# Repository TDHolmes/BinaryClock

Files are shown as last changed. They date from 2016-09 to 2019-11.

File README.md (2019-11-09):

# Binary Clock
A simple but well designed clock that displays the time in [binary coded decimal][BCD wiki link]

## PCB

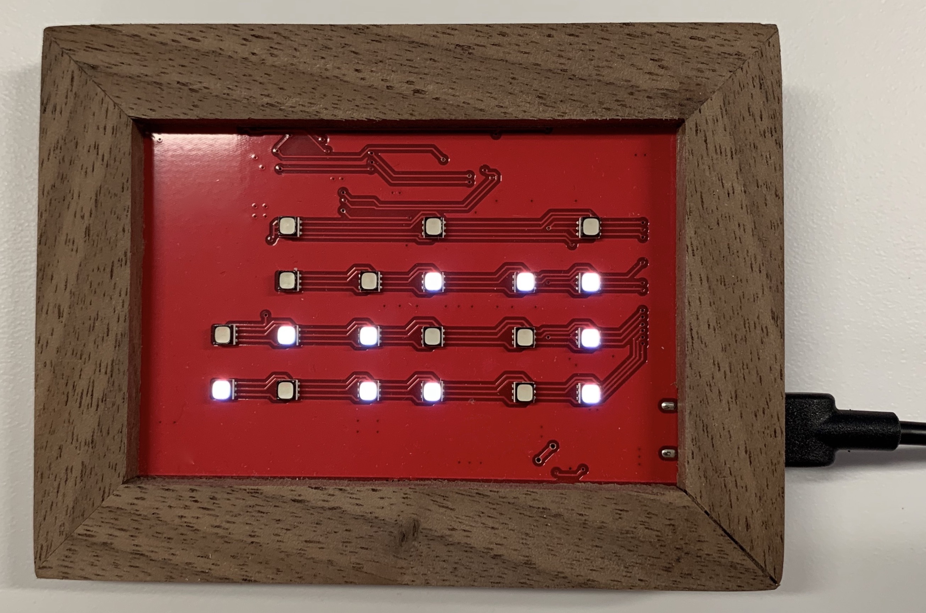
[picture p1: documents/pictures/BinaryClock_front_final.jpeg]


The current design uses an Atmel [ATtiny4313][attiny link] microcontroller in conjunction with a Maxim [DS3231M][ds3231m link] [RTC][RTC wiki link] for accurate time keeping. The LEDs are driven with a [STP16CPC26][stp16cpc26 link] constant current LED driver along with [high-side MOSFETs][mosfet wiki link] for [multiplexing][multiplexing wiki link].

## LED Driving Scheme

The LEDs are driven by multiplexing the rows and columns. The columns are dirven individually via PMOS transistors. The rows are daisy chained and driven by the [STP16CPC26][stp16cpc26 link]. The columns are refreshed at an effective rate of 360 Hz to be equivallent to 60 Hz refresh rate.

In order to get more than basic red, green and blue combinations, the LEDs have four time slots to create more color combinations. So in reality, the LEDs are updated at (60 Hz) * (6 columns) * (4 bit color) = 1440 Hz.

Below shows the connectivity of the LEDs to the driver chips.



Below is a snapshot in time when the minute ones column is active.



Below is a gif of multiplexing in action.

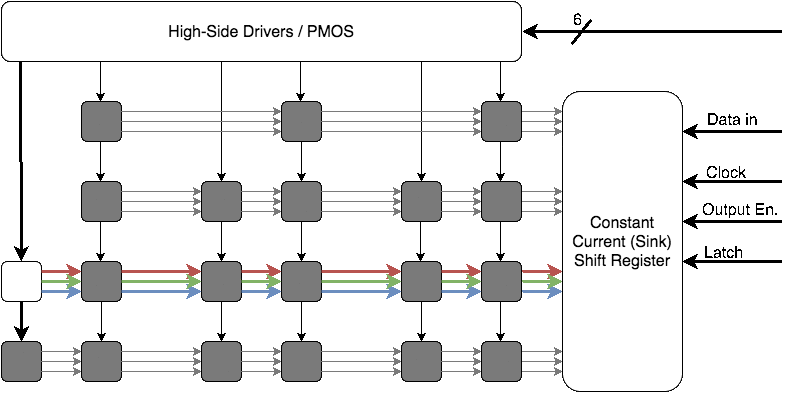
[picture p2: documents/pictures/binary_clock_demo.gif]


## GUI
The user interface communicates to the PCB via a [UART][UART wiki link] through a USB to serial converter chip. The user interface can do a few things:
- set the time to the current computer system time
- set a custom time
- set one or all LEDs to a certain color
- clear one or all LEDs

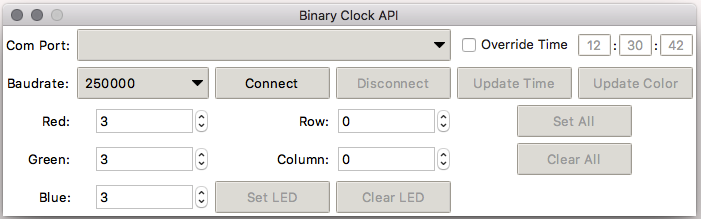
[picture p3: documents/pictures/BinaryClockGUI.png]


[BCD wiki link]: https://en.wikipedia.org/wiki/Binary-coded_decimal
[attiny link]: http://www.atmel.com/devices/ATTINY4313.aspx
[ds3231m link]: https://www.maximintegrated.com/en/products/digital/real-time-clocks/DS3231M.html
[stp16cpc26 link]: http://www.st.com/content/st_com/en/products/power-management/led-drivers/led-array-drivers/stp16cpc26.html
[Multiplex - off]: https://raw.githubusercontent.com/TDHolmes/BinaryClock/master/documents/pictures/binaryClock_multiplexLogic_notOn.png "Diagram of the connections if the LEDs"
[Multiplex - on]: https://raw.githubusercontent.com/TDHolmes/BinaryClock/master/documents/pictures/binaryClock_multiplexLogic_on.png "Diagram of a snapshot when the minute ones column is active."
[Multiplex - gif]: https://raw.githubusercontent.com/TDHolmes/BinaryClock/master/documents/pictures/binary_clock_demo.gif "Live gif of the multiplexing."
[PCB picture]: https://raw.githubusercontent.com/TDHolmes/BinaryClock/master/documents/pictures/BinaryClock_front_final.jpeg "final Binary Clock displaying 12:35:47"
[RTC wiki link]: https://en.wikipedia.org/wiki/Real-time_clock
[mosfet wiki link]: https://en.wikipedia.org/wiki/MOSFET#Single-type
[multiplexing wiki link]: https://en.wikipedia.org/wiki/Multiplexing
[GUI picture]: https://raw.githubusercontent.com/TDHolmes/BinaryClock/master/documents/pictures/BinaryClockGUI.png "Binary Clock GUI v1.0"
[UART wiki link]: https://en.wikipedia.org/wiki/Universal_asynchronous_receiver/transmitter

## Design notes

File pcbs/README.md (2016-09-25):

# Binary-Clock-v2.0
Board and schematic for the binary clock project.

<br />This work is licensed under a <a rel="license" href="http://creativecommons.org/licenses/by-nc-sa/4.0/">Creative Commons Attribution-NonCommercial-ShareAlike 4.0 International License</a>.

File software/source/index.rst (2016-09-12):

.. Binary Clock Software documentation master file, created by
   sphinx-quickstart on Sun Sep 11 17:31:34 2016.
   You can adapt this file completely to your liking, but it should at least
   contain the root `toctree` directive.

Welcome to Binary Clock Software's documentation!
=================================================

.. toctree::
   :maxdepth: 2

Binary Clock Python API
-----------------------

.. automodule:: binaryClockAPI

=====================
BinaryClockAPI Class
=====================

.. currentmodule:: binaryClockAPI
.. autoclass:: BinaryClockAPI
    :private-members:
    :members:

Binary Clock GUI
----------------

.. automodule:: binaryClockGUI

=====================
BinaryClockGUI Class
=====================

.. currentmodule:: binaryClockGUI
.. autoclass:: BinaryClockGUI
    :private-members:
    :members:

GUI Helper Functions
--------------------

.. automodule:: CustomGUIWrappers
.. currentmodule:: CustomGUIWrappers

=================
CheckBox Class
=================

.. autoclass:: CheckBox 
   :private-members:
   :members:

=================
EntryBox Class
=================

.. autoclass:: EntryBox 
   :private-members:
   :members:

=================
Dropdown Class
=================

.. autoclass:: Dropdown 
   :private-members:
   :members:

============
Labels Class
============

.. autoclass:: Labels 
   :private-members:
   :members:

=================
ScrollBox Class
=================

.. autoclass:: ScrollBox 
   :private-members:
   :members:

============
Button Class
============

.. autoclass:: Button 
   :private-members:
   :members:

=================
TimeEntry Class
=================

.. autoclass:: TimeEntry 
   :private-members:
   :members:

Indices and tables
==================

* :ref:`genindex`
* :ref:`modindex`
* :ref:`search`

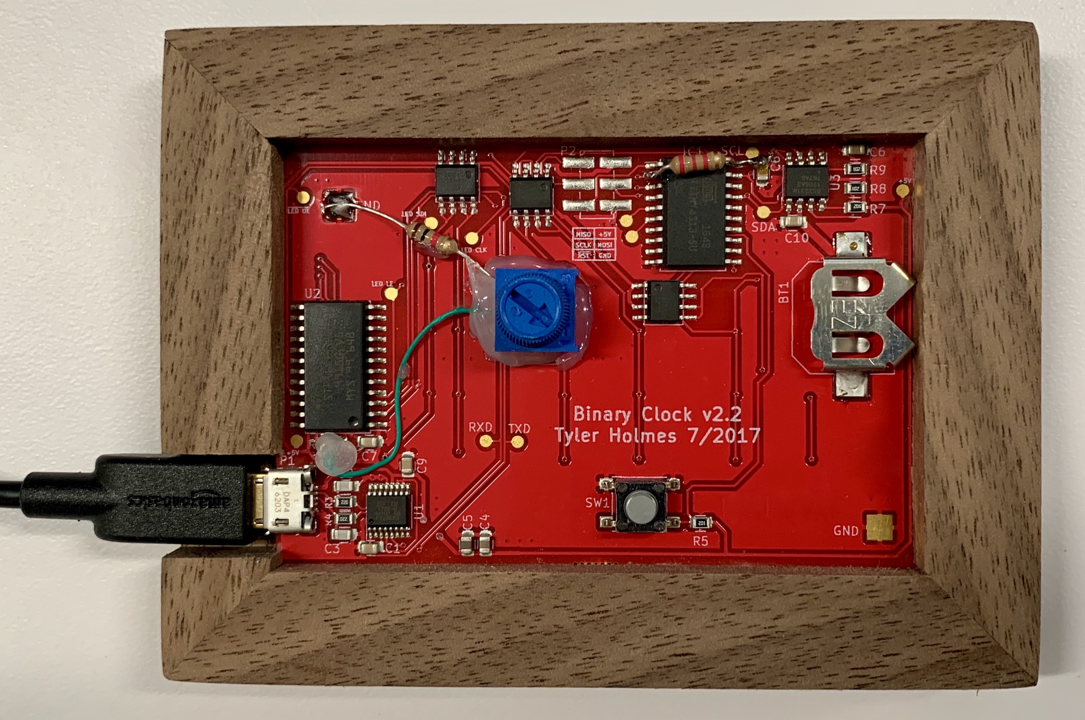
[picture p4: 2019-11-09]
documents/pictures/BinaryClock_back_final.jpeg

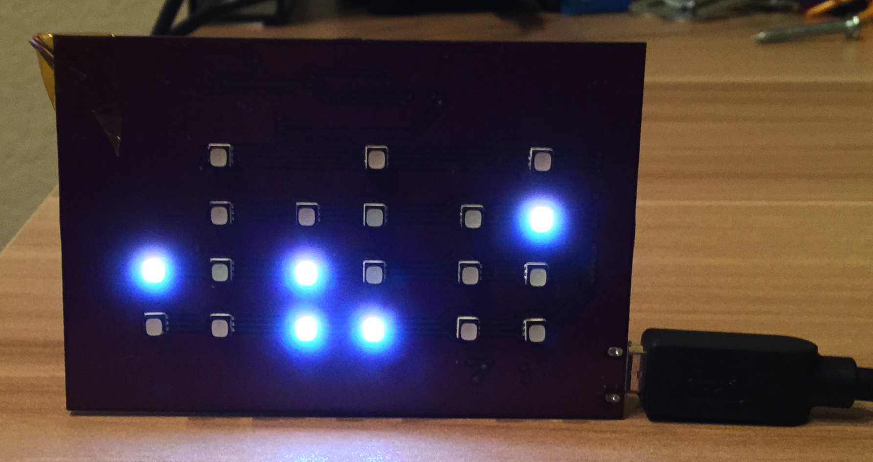
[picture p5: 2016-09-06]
documents/pictures/BinaryClock_rev1.JPG

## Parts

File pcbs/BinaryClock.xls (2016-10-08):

Id | Designator | Package | Quantity | Designation | MPN
3 | C3,C2 | C_0805 | 2 | 47 pF | 885012007032
4 | C4 | C_0805 | 1 | 1 uF | CC0805KKX7R7BB105
6 | C5 | C_0805 | 1 | 4.7 uF | GRM21BR61E475KA12L
7 | Q2,Q1,Q3 | SOIC-8-N | 3 | DMG9933USD | DMG9933USD-13DICT-ND
8 | BT1 | S8201-46R | 1 | CR1220 | S8201-46R
9 | U3 | SOIC-8_3.9x4.9mm_Pitch1.27mm | 1 | DS3231M | DS3231MZ/V+
10 | IC1 | SOIC-20_7.5x12.8mm_Pitch1.27mm | 1 | ATTINY2313A-S | ATtiny4313
11 | D_M_8,D_S_40,D_S_20,D_S_10,D_S_8,D_S_4,D_S_2,D_S_1,D_M_40,D_M_20,D_M_10,D_M_4,D_M_2,D_M_1,D_H_20,D_H_10,D_H_8,D_H_4,D_H_2,D_H_1 | CREELED_6 | 20 | CLY6D-FKC | CLY6D-FKC-CK1N1D1BB7D3D3
12 | SW1 | SW_SPST_PTS645 | 1 | SW_PUSH | PTS645SH50SMTR92 LFS
13 | R5,R9,R8,R7 | R_0805 | 4 | 1K | RC0805JR-071KL
14 | R6 | R_0805 | 1 | 2K | RC0805JR-072KL
15 | R3,R4 | R_0805 | 2 | R27 | RC0805JR-0727RL
16 | P1 | 2013499-1 | 1 | USB_OTG | 2013499-1
17 | U2 | SOIC-24_7.5x15.4mm_Pitch1.27mm | 1 | STP16CPC26 | STP16CPC26MTR
18 | P2 | 2x3_header_smd_0.1in | 1 | CONN_02X03 | 15910060
19 | U1 | SSOP-16_3.9x4.9mm_Pitch0.635mm | 1 | FT230XS | FT230XS-U
20 | C1 | C_0805 | 1 | 0.1 uF | C0805C104K3RACTU
21 | C7,C10,C6,C8,C9 | C_0805 | 6 | 0.1 uF | C0805C104K3RACTU

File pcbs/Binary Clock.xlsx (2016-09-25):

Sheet: Parts
Qty | Part Number | Description | Cost per 1 | Cost per 100 | Net (per 1) | Net (per 100) | datasheet
1 | STP16CPC26MTR | 16 bit constant current sink | $0.75 | $0.57 | $0.75 | $0.57 | http://www.st.com/content/ccc/resource/technical/document/datasheet/5c/ed/b3/8b/32/99/4d/cd/CD00298756.pdf/files/CD00298756.pdf/jcr:content/translations/en.CD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
1 | ATtiny4313 | ATtiny 20 MHz 8-Bit Micro - SOIC-20 | $1.84 | $1.33 | $1.84 | $1.33 | http://www.atmel.com/images/doc8246.pdf
20 | CLY6D-FKC-CK1N1D1BB7D3D3 | RGB LED | $0.37 | $0.32 | $7.40 | $6.40 | http://www.cree.com/~/media/Files/Cree/LED-Components-and-Modules/HB/Data-Sheets/1321-CLY6D-FKC.pdf
3 | DMG9933USD-13DICT-ND | P-FET transistors. pair (SOIC-8) | $0.41 | $0.26 | $1.23 | $0.78 | http://www.diodes.com/_files/datasheets/ds32085.pdf
1 | FT230XS-U | USB to serial converter | $2.04 | $1.90 | $2.04 | $1.90 | http://www.ftdichip.com/Support/Documents/DataSheets/ICs/DS_FT230X.pdf
1 | 2013499-1 | micro USB connector | $1.78 | $1.38 | $1.78 | $1.38 | http://www.te.com/usa-en/product-2013499-1.html
1 | DS3231MZ/V+ | High Accuracy RTC w/ internal osc. | $6.46 | $4.81 | $6.46 | $4.81 | https://datasheets.maximintegrated.com/en/ds/DS3231M.pdf
1 | 15910060 | 6 pos prog header | $0.57 | $0.37 | $0.57 | $0.37 | http://www.digikey.com/product-detail/en/molex-llc/0015916062/WM6888CT-ND/3044894
1 | PTS645SH50SMTR92 LFS | tac switch | $0.21 | $0.18 | $0.21 | $0.18 | http://www.ck-components.com/media/1471/pts645.pdf
6 |  | 1k resistors
1 |  | 2k resistors |  |  |  |  | Dimensions (in): | 2 | 3
4 |  | .1 uF
1 |  | 1 uF
2 |  | 10 uF
 |  |  |  | Total: | $22.28 | $17.71
 | Board Fabrication, 2 layer | PCB Way |  | $1.51 |  | $0.00
1 |  | Dirty PCB |  | $2.42 |  | $2.42
 |  | Sunstone (USA) |  | $7.66 |  | $0.00
1 | Fab | PCB-CART |  | $4.15 |  | $7.40
 |  | PCB-NG |  | $72.00 |  | $0.00
 |  | PCB Assembly Express |  | $7.70 |  | $0.00
 |  |  |  |  | Total: | $9.82
 |  |  |  | Grand Total: | $32.10 | $27.53
 | Cost for 100: |  |  | Cost for X: | 50 | $1,376.57
 |  |  |  | Price Sold At: |  | $64.20
 |  |  |  | Number sold to recop |  | 22
 |  |  |  | Total Profit: |  | $1,833.21
 | SMD Trimmer | http://www.digikey.com/product-detail/en/copal-electronics-inc/ST4ETB102/ST4ETB102CT-ND/738512

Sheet: Sheet3
Qty | Part Number | Description
1 | STP16CPC26MTR | 16 bit constant current sink
1 | ATtiny4313 | ATtiny 20 MHz 8-Bit Micro - SOIC-20
20 | CLY6D-FKC-CK1N1D1BB7D3D3 | RGB LED
3 | DMG9933USD-13DICT-ND | P-FET transistors. pair (SOIC-8)
1 | FT230XS-U | USB to serial converter
1 | 2013499-1 | micro USB connector
1 | DS3231MZ/V+ | High Accuracy RTC w/ internal osc.
1 | 15910060 | 6 pos prog header
1 | PTS645SH50SMTR92 LFS | tac switch
6 |  | 1k resistors
1 |  | 2k resistors
4 |  | .1 uF
1 |  | 1 uF
2 |  | 10 uF

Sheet: Timing
Attiny Frequency: | 8,000,000 | Hz
Clks per bit: | 40 | clks | (1/2 the freqency of the micro + 16 data bits + Latching & output)
N bit Color: | 8 | bits
N rows to multiplex: | 12
Total Update Rate | 120 | Hz
Wait Time per Bit: | 0.562 | ms
Setup Time per Bit: | 0.480 | ms

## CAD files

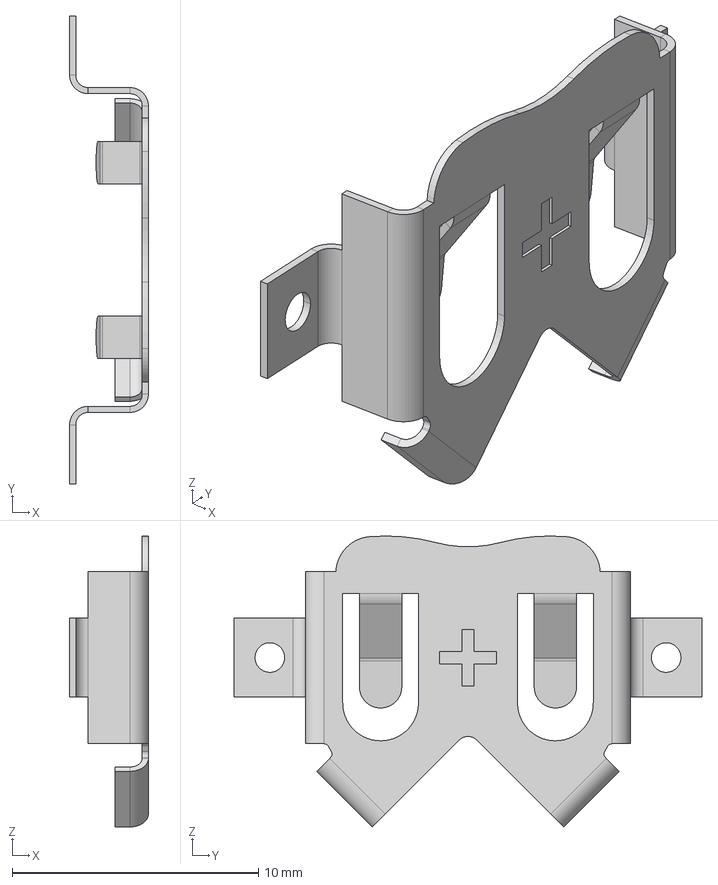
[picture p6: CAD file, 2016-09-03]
pcbs/coincellholder/s8201-46r/s8201-46r.stp
3.20 x 19.0 x 11.8 mm

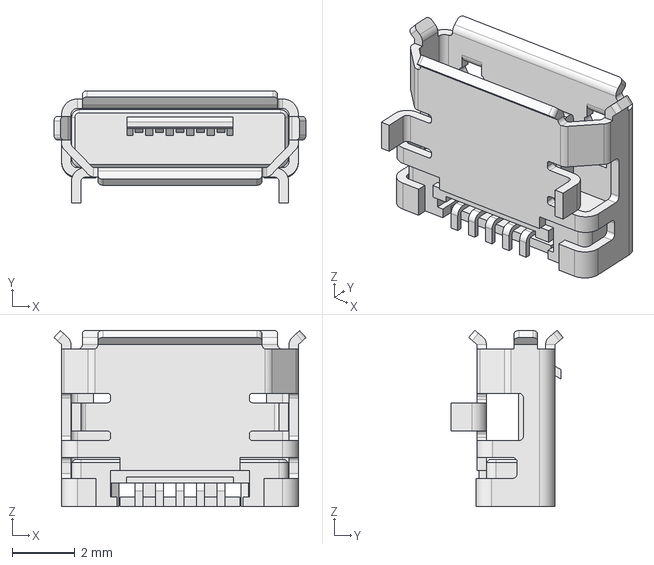
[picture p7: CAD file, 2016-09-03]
pcbs/microUSB/c-2013499-1-e-3d.FCStd
8.00 x 3.57 x 5.60 mm

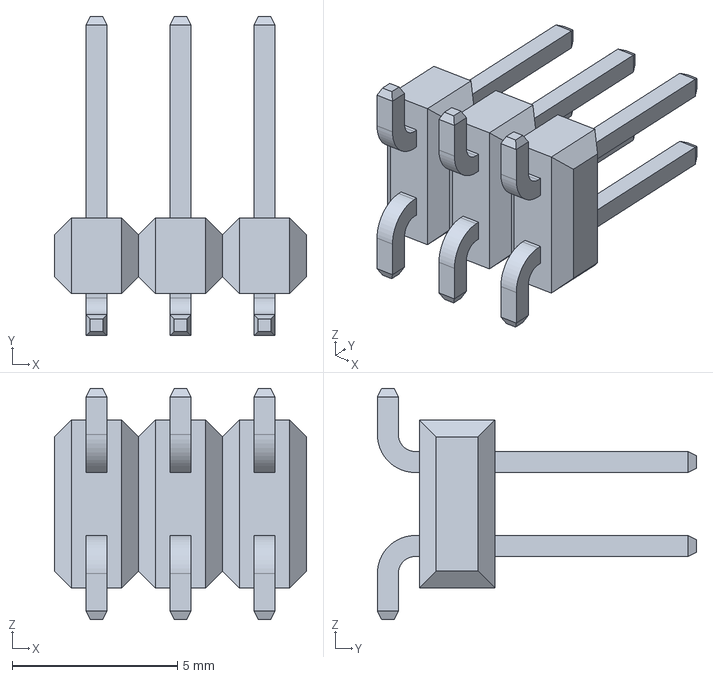
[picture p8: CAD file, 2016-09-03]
pcbs/header/015910060.stp
7.62 x 9.65 x 6.99 mm

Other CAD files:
pcbs/coincellholder/s8201-46r/s8201-46r.igs
pcbs/coincellholder/s8201-46r/s8201-46r.obj
pcbs/header/015910060.obj
pcbs/microUSB/c-2013499-1-e-3d.igs
pcbs/microUSB/c-2013499-1-e-3d.obj

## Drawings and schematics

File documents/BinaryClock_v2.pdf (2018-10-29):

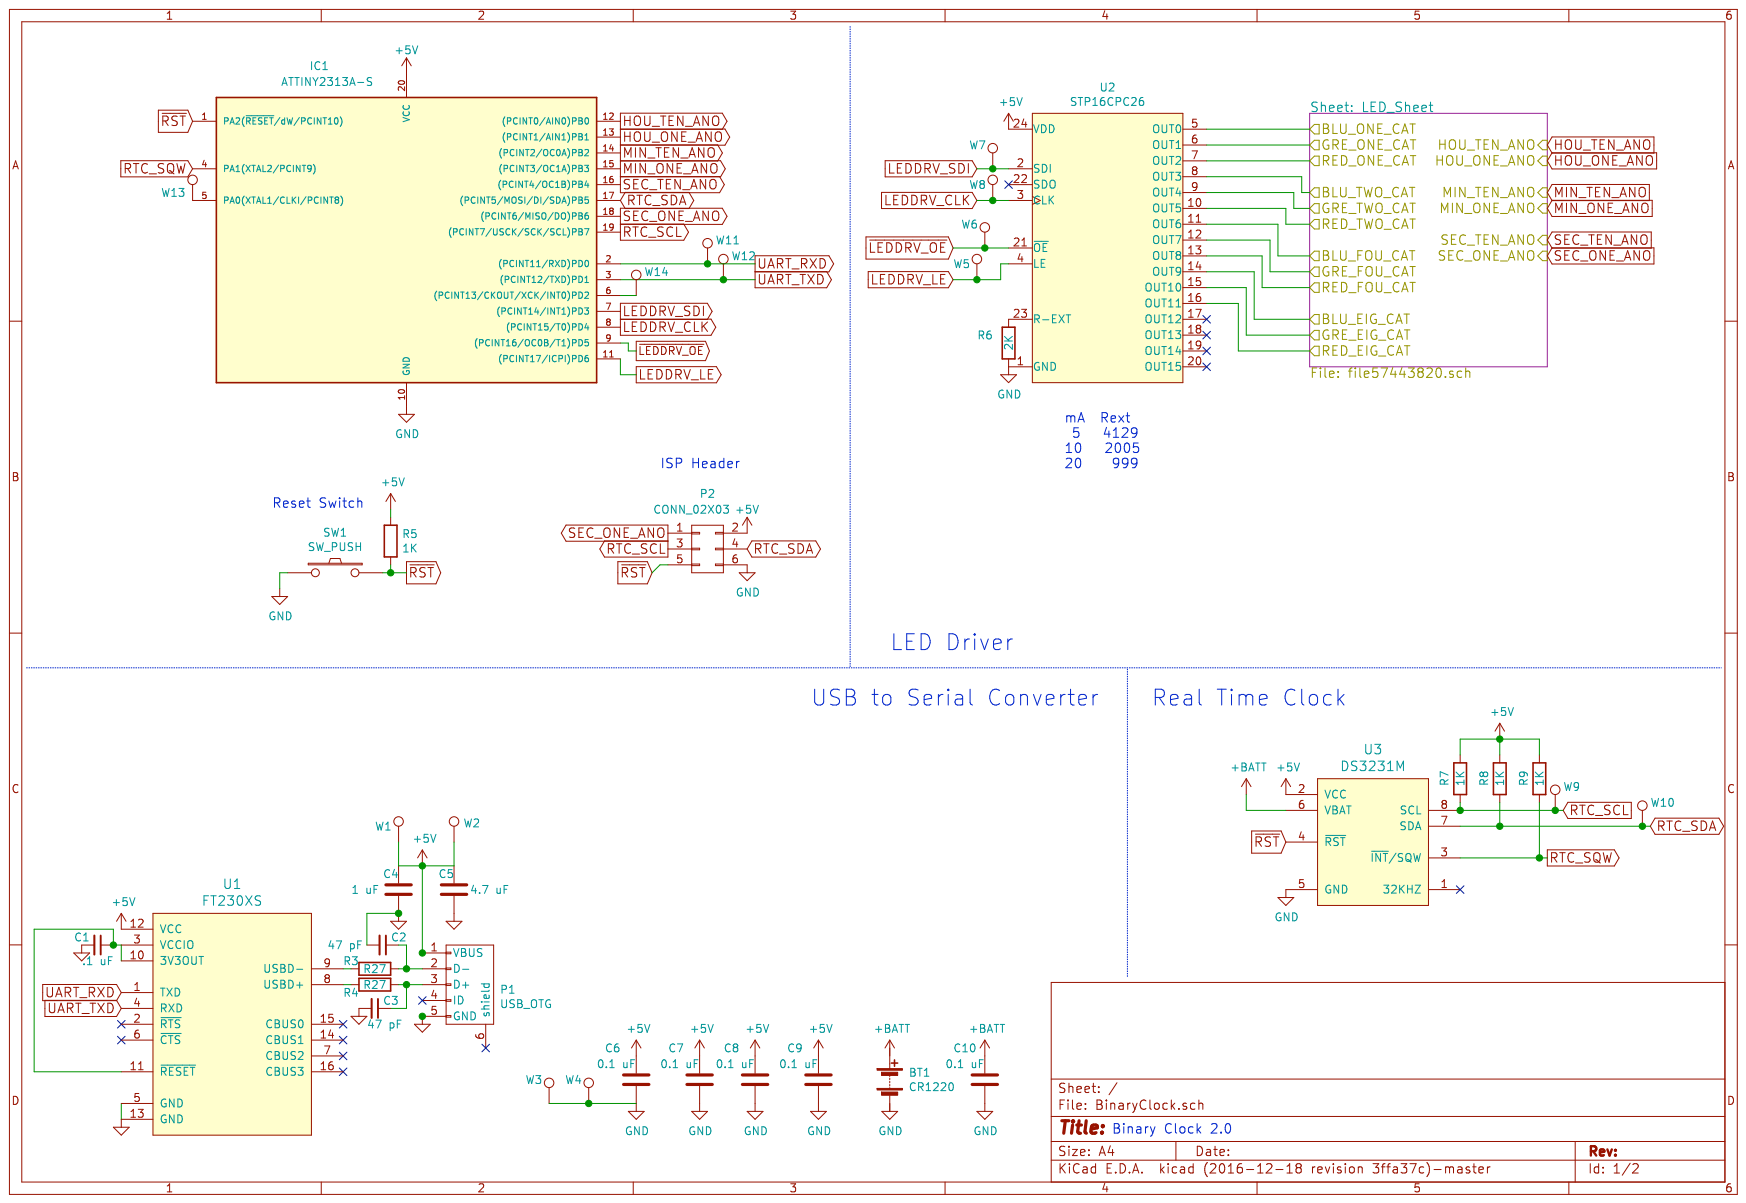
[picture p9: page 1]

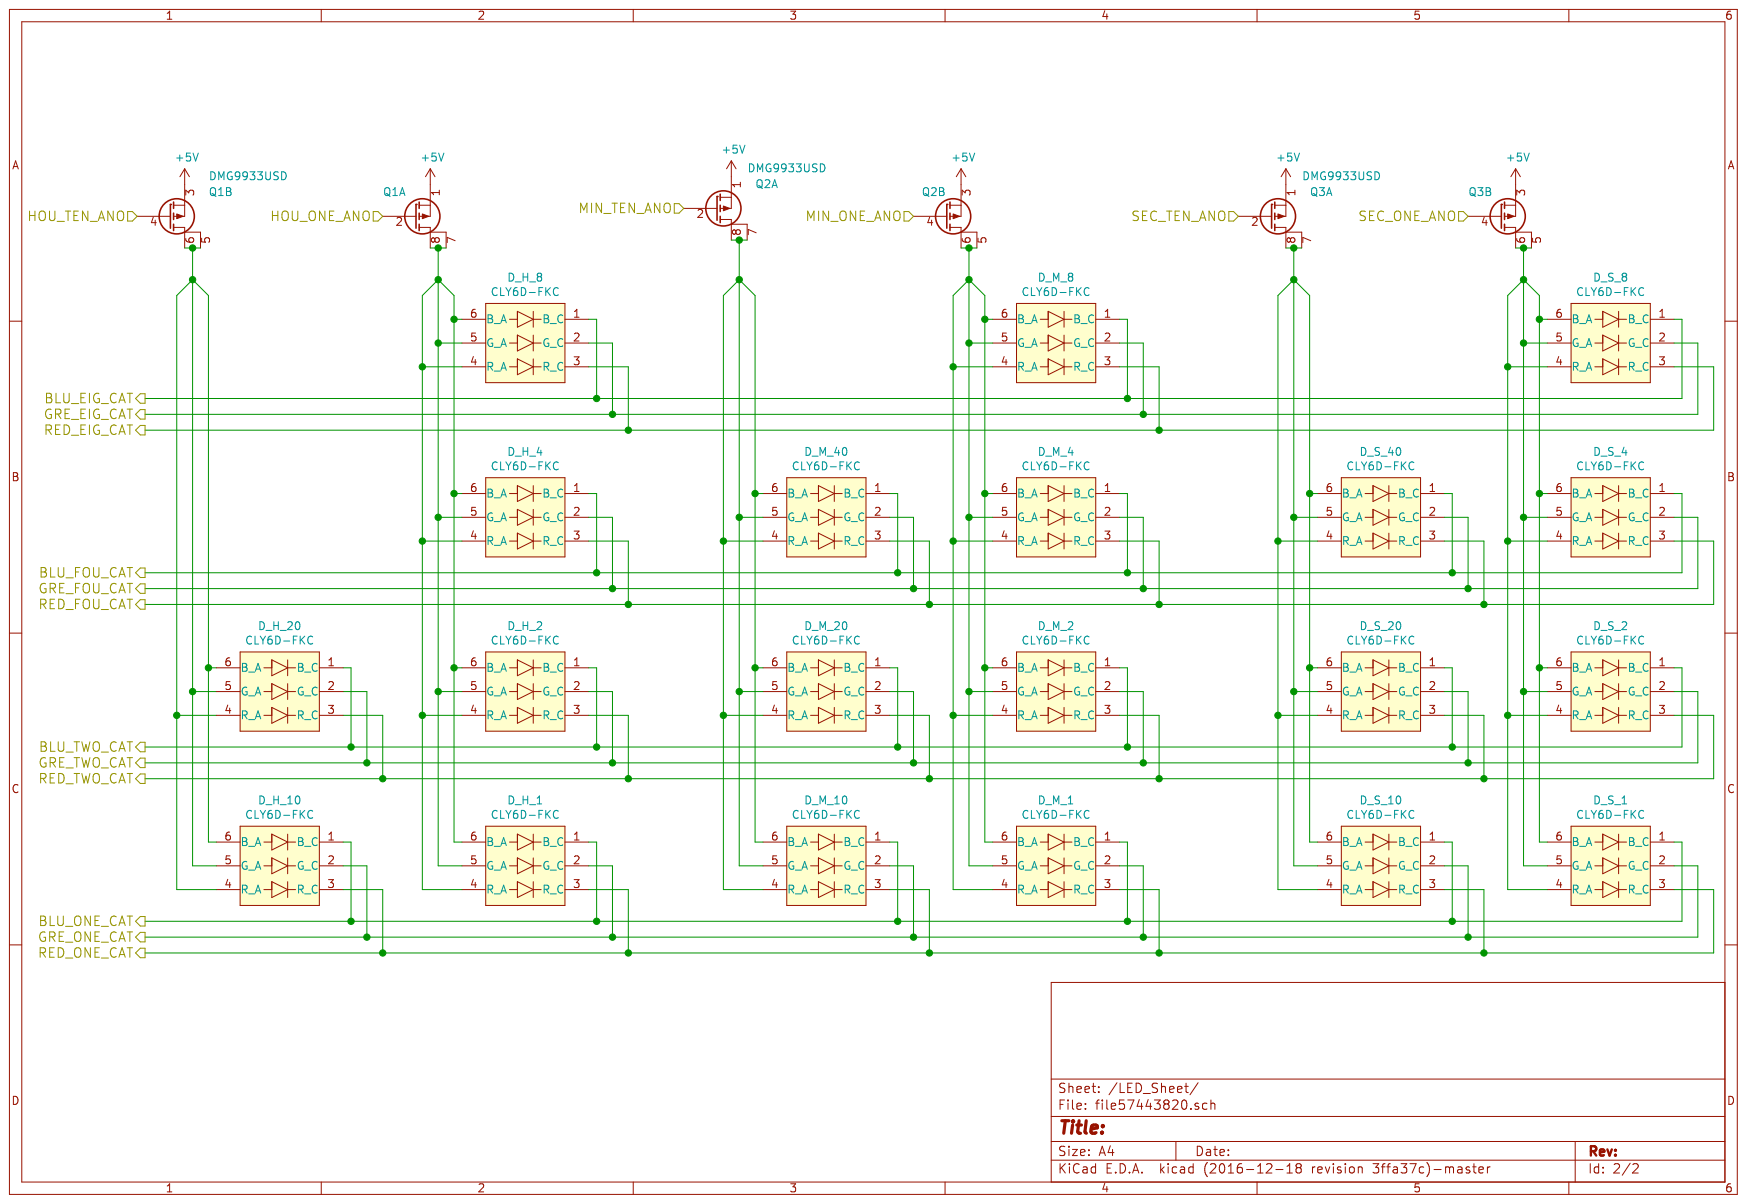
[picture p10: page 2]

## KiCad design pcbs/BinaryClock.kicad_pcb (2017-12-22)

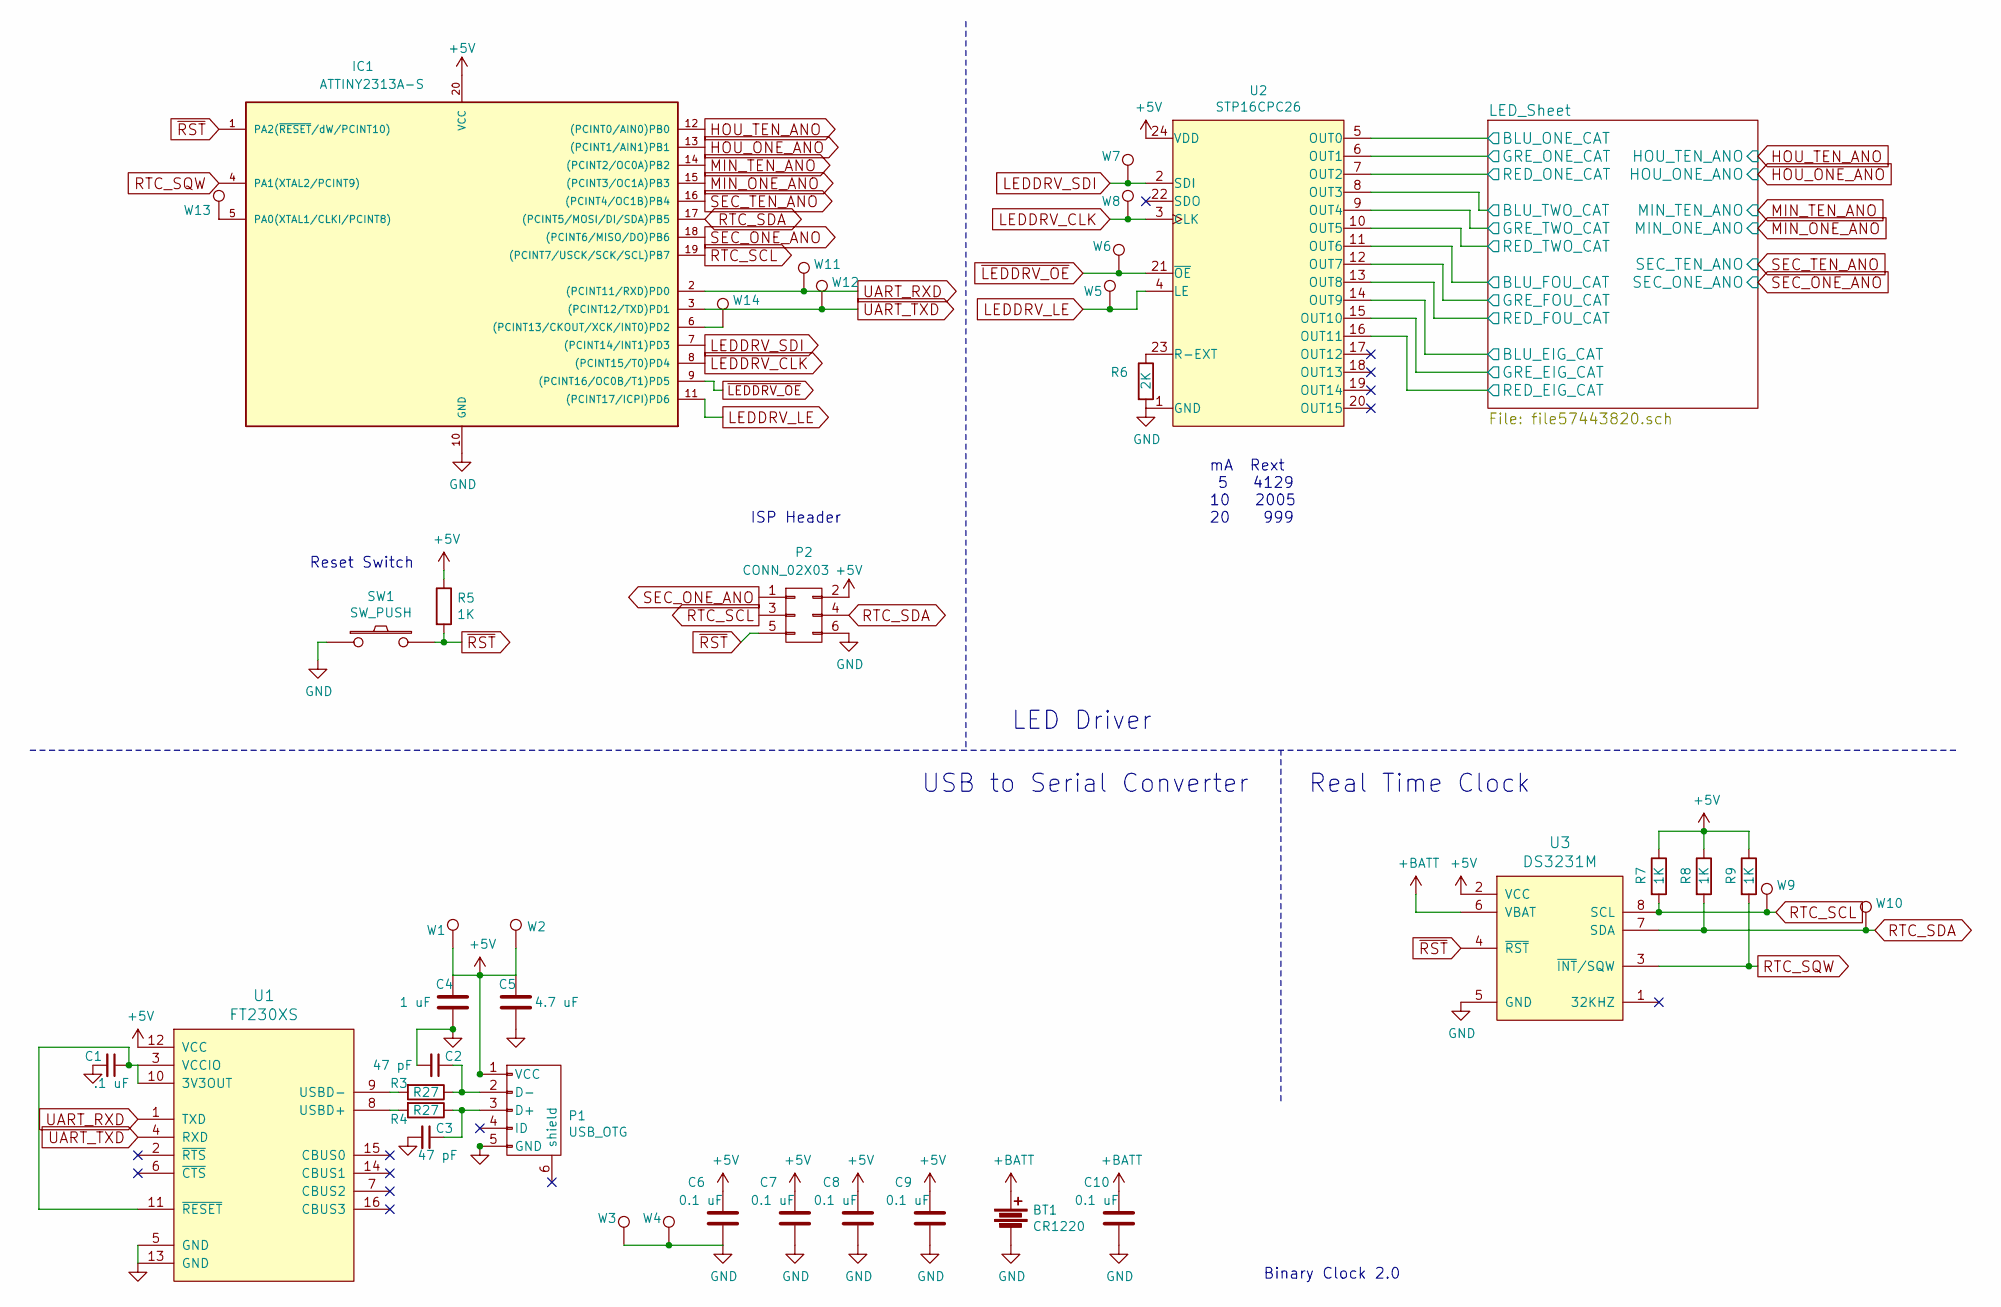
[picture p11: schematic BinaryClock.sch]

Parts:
BT1: CR1220; S8201-46R
C1: .1 uF; C_0805
C2: 47 pF
C3: 47 pF; C_0805
C4: 1 uF; R_0805
C5: 4.7 uF; R_0805
C6, C7, C8, C9, C10: 0.1 uF; R_0805
IC1: ATTINY2313A-S; SOIC-20_7.5x12.8mm_Pitch1.27mm
P1: USB_OTG; 2013499-1
P2: CONN_02X03; 2x3_header_smd_0.1in
R3, R4: R27; R_0805
R5, R7, R8, R9: 1K; R_0805
R6: 2K; R_0805
SW1: SW_PUSH; SW_SPST_PTS645
U1: FT230XS; SSOP-16_3.9x4.9mm_Pitch0.635mm
U2: STP16CPC26; SOIC-24_7.5x15.4mm_Pitch1.27mm
U3: DS3231M; SOIC-8_3.9x4.9mm_Pitch1.27mm
W1, W2, W3, W4: TEST_1P; Measurement_Point_Square-SMD-Pad_Big
W5, W6, W7, W8, W9, W10, W11, W12, W13, W14: TEST_1P; Measurement_Point_Round-SMD-Pad_Small

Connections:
+5V: C4.1, C5.1, C6.1, C7.1, C8.1, C9.1, IC1.20 (VCC), P1.1 (VCC), P2.2, R5.1, R7.1, R8.1, R9.1, U1.12 (VCC), U2.24 (VDD), U3.2 (VCC), W1.1, W2.1; also elsewhere on the board
+BATT: BT1.1, C10.1, U3.6 (VBAT)
/LED_Sheet/BLU_EIG_CAT: U2.14 (OUT9); also elsewhere on the board
/LED_Sheet/BLU_FOU_CAT: U2.11 (OUT6); also elsewhere on the board
/LED_Sheet/BLU_ONE_CAT: U2.5 (OUT0); also elsewhere on the board
/LED_Sheet/BLU_TWO_CAT: U2.8 (OUT3); also elsewhere on the board
/LED_Sheet/GRE_EIG_CAT: U2.15 (OUT10); also elsewhere on the board
/LED_Sheet/GRE_FOU_CAT: U2.12 (OUT7); also elsewhere on the board
/LED_Sheet/GRE_ONE_CAT: U2.6 (OUT1); also elsewhere on the board
/LED_Sheet/GRE_TWO_CAT: U2.9 (OUT4); also elsewhere on the board
/LED_Sheet/RED_EIG_CAT: U2.16 (OUT11); also elsewhere on the board
/LED_Sheet/RED_FOU_CAT: U2.13 (OUT8); also elsewhere on the board
/LED_Sheet/RED_ONE_CAT: U2.7 (OUT2); also elsewhere on the board
/LED_Sheet/RED_TWO_CAT: U2.10 (OUT5); also elsewhere on the board
GND: BT1.2, C1.2, C2.2, C3.2, C4.2, C5.2, C6.2, C7.2, C8.2, C9.2, C10.2, IC1.10 (GND), P1.5 (GND), P2.6, R6.2, SW1.1, U1.5 (GND), U1.13 (GND), U2.1 (GND), U3.5 (GND), W3.1, W4.1
HOU_ONE_ANO: IC1.13 ((PCINT1/AIN1)PB1); also elsewhere on the board
HOU_TEN_ANO: IC1.12 ((PCINT0/AIN0)PB0); also elsewhere on the board
LEDDRV_CLK: IC1.8 ((PCINT15/T0)PD4), U2.3 (CLK), W8.1
LEDDRV_LE: IC1.11 ((PCINT17/ICPI)PD6), U2.4 (LE), W5.1
LEDDRV_SDI: IC1.7 ((PCINT14/INT1)PD3), U2.2 (SDI), W7.1
MIN_ONE_ANO: IC1.15 ((PCINT3/OC1A)PB3); also elsewhere on the board
MIN_TEN_ANO: IC1.14 ((PCINT2/OC0A)PB2); also elsewhere on the board
unnamed: C1.1, U1.3 (VCCIO), U1.10 (3V3OUT), U1.11 (~RESET)
unnamed: C2.1, P1.2 (D-), R3.1
unnamed: C3.1, P1.3 (D+), R4.1
unnamed: IC1.5 (PA0(XTAL1/CLKI/PCINT8)), W13.1
unnamed: IC1.6 ((PCINT13/CKOUT/XCK/INT0)PD2), W14.1
unnamed: R3.2, U1.9 (USBD-)
unnamed: R4.2, U1.8 (USBD+)
unnamed: R6.1, U2.23 (R-EXT)
RTC_SCL: IC1.19 ((PCINT7/USCK/SCK/SCL)PB7), P2.3, R7.2, U3.8 (SCL), W9.1
RTC_SDA: IC1.17 ((PCINT5/MOSI/DI/SDA)PB5), P2.4, R8.2, U3.7 (SDA), W10.1
RTC_SQW: IC1.4 (PA1(XTAL2/PCINT9)), R9.2, U3.3 (~INT~/SQW)
SEC_ONE_ANO: IC1.18 ((PCINT6/MISO/DO)PB6), P2.1; also elsewhere on the board
SEC_TEN_ANO: IC1.16 ((PCINT4/OC1B)PB4); also elsewhere on the board
UART_RXD: IC1.2 ((PCINT11/RXD)PD0), U1.1 (TXD), W11.1
UART_TXD: IC1.3 ((PCINT12/TXD)PD1), U1.4 (RXD), W12.1
~LEDDRV_OE: IC1.9 ((PCINT16/OC0B/T1)PD5), U2.21 (~OE), W6.1
~RST: IC1.1 (PA2(~RESET~/dW/PCINT10)), P2.5, R5.2, SW1.2, U3.4 (~RST)

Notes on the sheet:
mA Rext 5 4129 10 2005 20 999
ISP Header
Reset Switch
LED Driver
USB to Serial Converter
Real Time Clock
Binary Clock 2.0

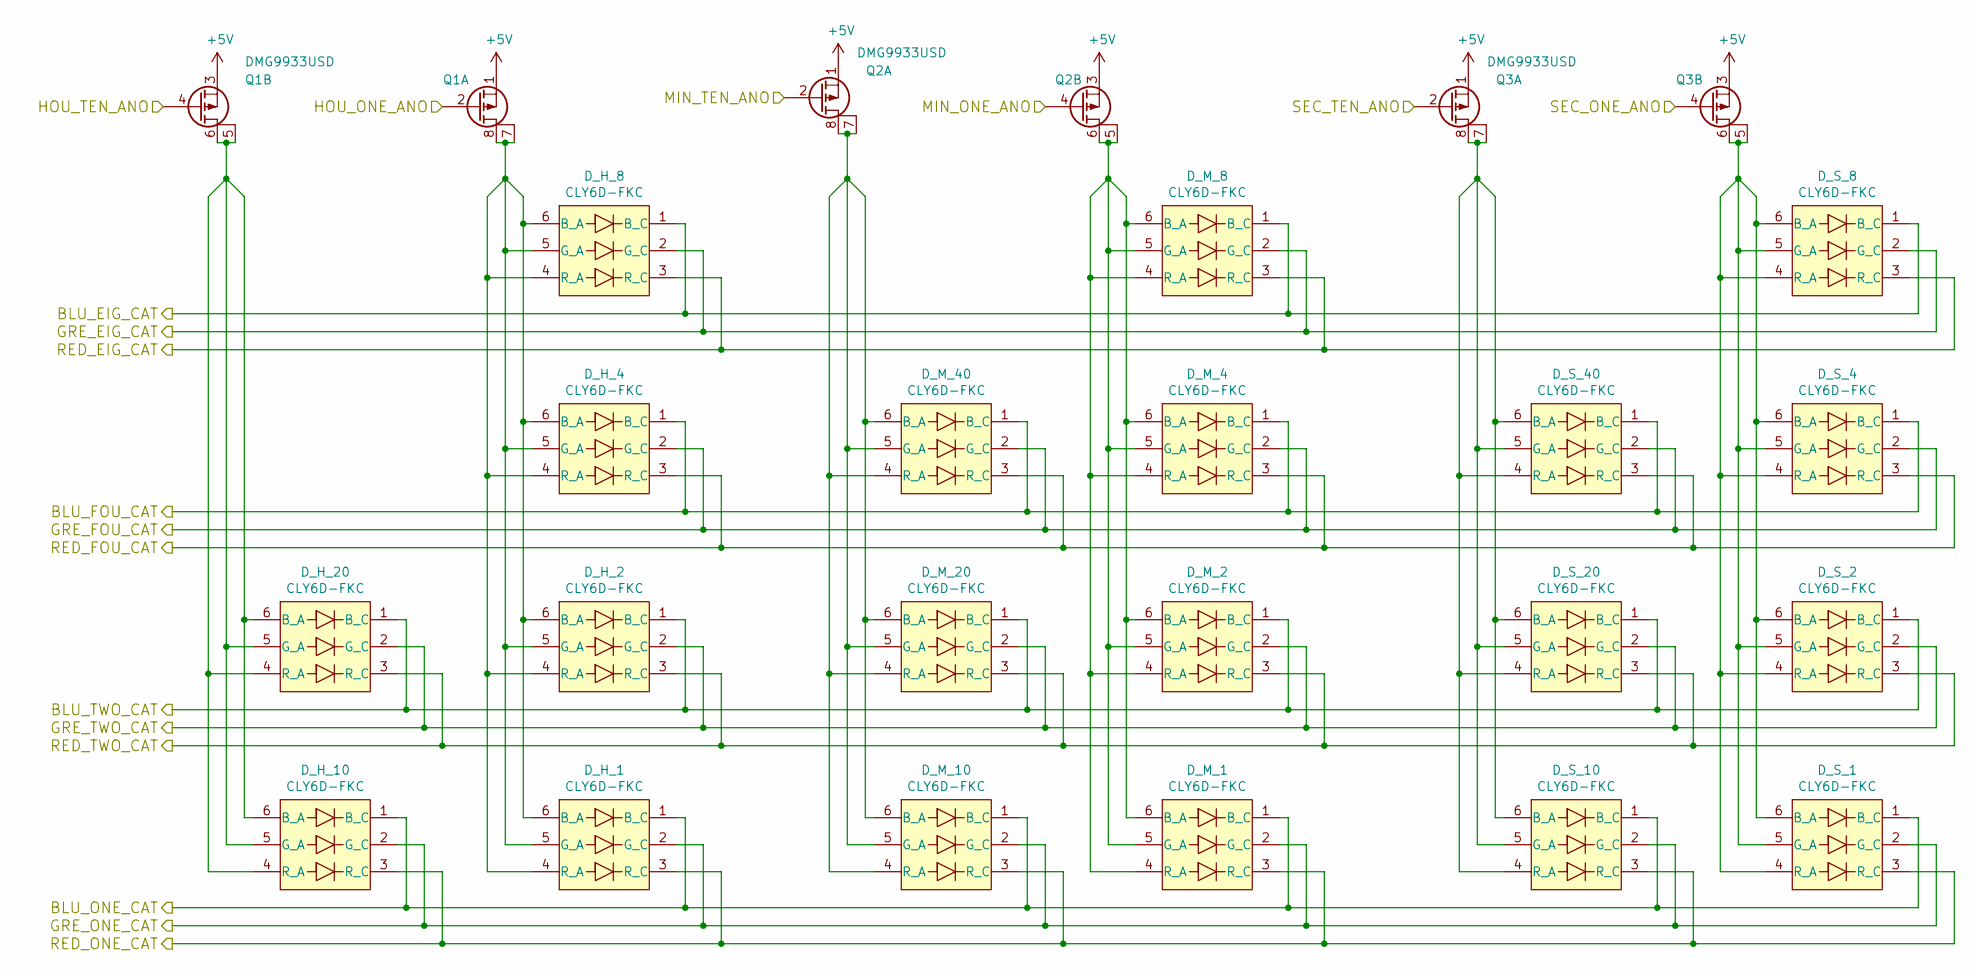
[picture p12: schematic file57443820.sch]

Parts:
D_H_1, D_H_2, D_H_4, D_H_8, D_H_10, D_H_20: CLY6D-FKC; CREELED_6
D_M_1, D_M_2, D_M_4, D_M_8, D_M_10, D_M_20, D_M_40: CLY6D-FKC; CREELED_6
D_S_1, D_S_2, D_S_4, D_S_8, D_S_10, D_S_20, D_S_40: CLY6D-FKC; CREELED_6
Q1, Q2, Q3: DMG9933USD; SOIC-8-N

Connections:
+5V: Q1.1 (S2), Q1.3 (S2), Q2.1 (S2), Q2.3 (S2), Q3.1 (S2), Q3.3 (S2); also elsewhere on the board
/LED_Sheet/BLU_EIG_CAT: D_H_8.1 (B_C), D_M_8.1 (B_C), D_S_8.1 (B_C); also elsewhere on the board
/LED_Sheet/BLU_FOU_CAT: D_H_4.1 (B_C), D_M_4.1 (B_C), D_M_40.1 (B_C), D_S_4.1 (B_C), D_S_40.1 (B_C); also elsewhere on the board
/LED_Sheet/BLU_ONE_CAT: D_H_1.1 (B_C), D_H_10.1 (B_C), D_M_1.1 (B_C), D_M_10.1 (B_C), D_S_1.1 (B_C), D_S_10.1 (B_C); also elsewhere on the board
/LED_Sheet/BLU_TWO_CAT: D_H_2.1 (B_C), D_H_20.1 (B_C), D_M_2.1 (B_C), D_M_20.1 (B_C), D_S_2.1 (B_C), D_S_20.1 (B_C); also elsewhere on the board
/LED_Sheet/GRE_EIG_CAT: D_H_8.2 (G_C), D_M_8.2 (G_C), D_S_8.2 (G_C); also elsewhere on the board
/LED_Sheet/GRE_FOU_CAT: D_H_4.2 (G_C), D_M_4.2 (G_C), D_M_40.2 (G_C), D_S_4.2 (G_C), D_S_40.2 (G_C); also elsewhere on the board
/LED_Sheet/GRE_ONE_CAT: D_H_1.2 (G_C), D_H_10.2 (G_C), D_M_1.2 (G_C), D_M_10.2 (G_C), D_S_1.2 (G_C), D_S_10.2 (G_C); also elsewhere on the board
/LED_Sheet/GRE_TWO_CAT: D_H_2.2 (G_C), D_H_20.2 (G_C), D_M_2.2 (G_C), D_M_20.2 (G_C), D_S_2.2 (G_C), D_S_20.2 (G_C); also elsewhere on the board
/LED_Sheet/RED_EIG_CAT: D_H_8.3 (R_C), D_M_8.3 (R_C), D_S_8.3 (R_C); also elsewhere on the board
/LED_Sheet/RED_FOU_CAT: D_H_4.3 (R_C), D_M_4.3 (R_C), D_M_40.3 (R_C), D_S_4.3 (R_C), D_S_40.3 (R_C); also elsewhere on the board
/LED_Sheet/RED_ONE_CAT: D_H_1.3 (R_C), D_H_10.3 (R_C), D_M_1.3 (R_C), D_M_10.3 (R_C), D_S_1.3 (R_C), D_S_10.3 (R_C); also elsewhere on the board
/LED_Sheet/RED_TWO_CAT: D_H_2.3 (R_C), D_H_20.3 (R_C), D_M_2.3 (R_C), D_M_20.3 (R_C), D_S_2.3 (R_C), D_S_20.3 (R_C); also elsewhere on the board
HOU_ONE_ANO: Q1.2 (G2); also elsewhere on the board
HOU_TEN_ANO: Q1.4 (G2); also elsewhere on the board
MIN_ONE_ANO: Q2.4 (G2); also elsewhere on the board
MIN_TEN_ANO: Q2.2 (G2); also elsewhere on the board
unnamed: D_H_1.4 (R_A), D_H_1.5 (G_A), D_H_1.6 (B_A), D_H_2.4 (R_A), D_H_2.5 (G_A), D_H_2.6 (B_A), D_H_4.4 (R_A), D_H_4.5 (G_A), D_H_4.6 (B_A), D_H_8.4 (R_A), D_H_8.5 (G_A), D_H_8.6 (B_A), Q1.7 (D2_2), Q1.8 (D2_1)
unnamed: D_H_10.4 (R_A), D_H_10.5 (G_A), D_H_10.6 (B_A), D_H_20.4 (R_A), D_H_20.5 (G_A), D_H_20.6 (B_A), Q1.5 (D2_2), Q1.6 (D2_1)
unnamed: D_M_1.4 (R_A), D_M_1.5 (G_A), D_M_1.6 (B_A), D_M_2.4 (R_A), D_M_2.5 (G_A), D_M_2.6 (B_A), D_M_4.4 (R_A), D_M_4.5 (G_A), D_M_4.6 (B_A), D_M_8.4 (R_A), D_M_8.5 (G_A), D_M_8.6 (B_A), Q2.5 (D2_2), Q2.6 (D2_1)
unnamed: D_M_10.4 (R_A), D_M_10.5 (G_A), D_M_10.6 (B_A), D_M_20.4 (R_A), D_M_20.5 (G_A), D_M_20.6 (B_A), D_M_40.4 (R_A), D_M_40.5 (G_A), D_M_40.6 (B_A), Q2.7 (D2_2), Q2.8 (D2_1)
unnamed: D_S_1.4 (R_A), D_S_1.5 (G_A), D_S_1.6 (B_A), D_S_2.4 (R_A), D_S_2.5 (G_A), D_S_2.6 (B_A), D_S_4.4 (R_A), D_S_4.5 (G_A), D_S_4.6 (B_A), D_S_8.4 (R_A), D_S_8.5 (G_A), D_S_8.6 (B_A), Q3.5 (D2_2), Q3.6 (D2_1)
unnamed: D_S_10.4 (R_A), D_S_10.5 (G_A), D_S_10.6 (B_A), D_S_20.4 (R_A), D_S_20.5 (G_A), D_S_20.6 (B_A), D_S_40.4 (R_A), D_S_40.5 (G_A), D_S_40.6 (B_A), Q3.7 (D2_2), Q3.8 (D2_1)
SEC_ONE_ANO: Q3.4 (G2); also elsewhere on the board
SEC_TEN_ANO: Q3.2 (G2); also elsewhere on the board

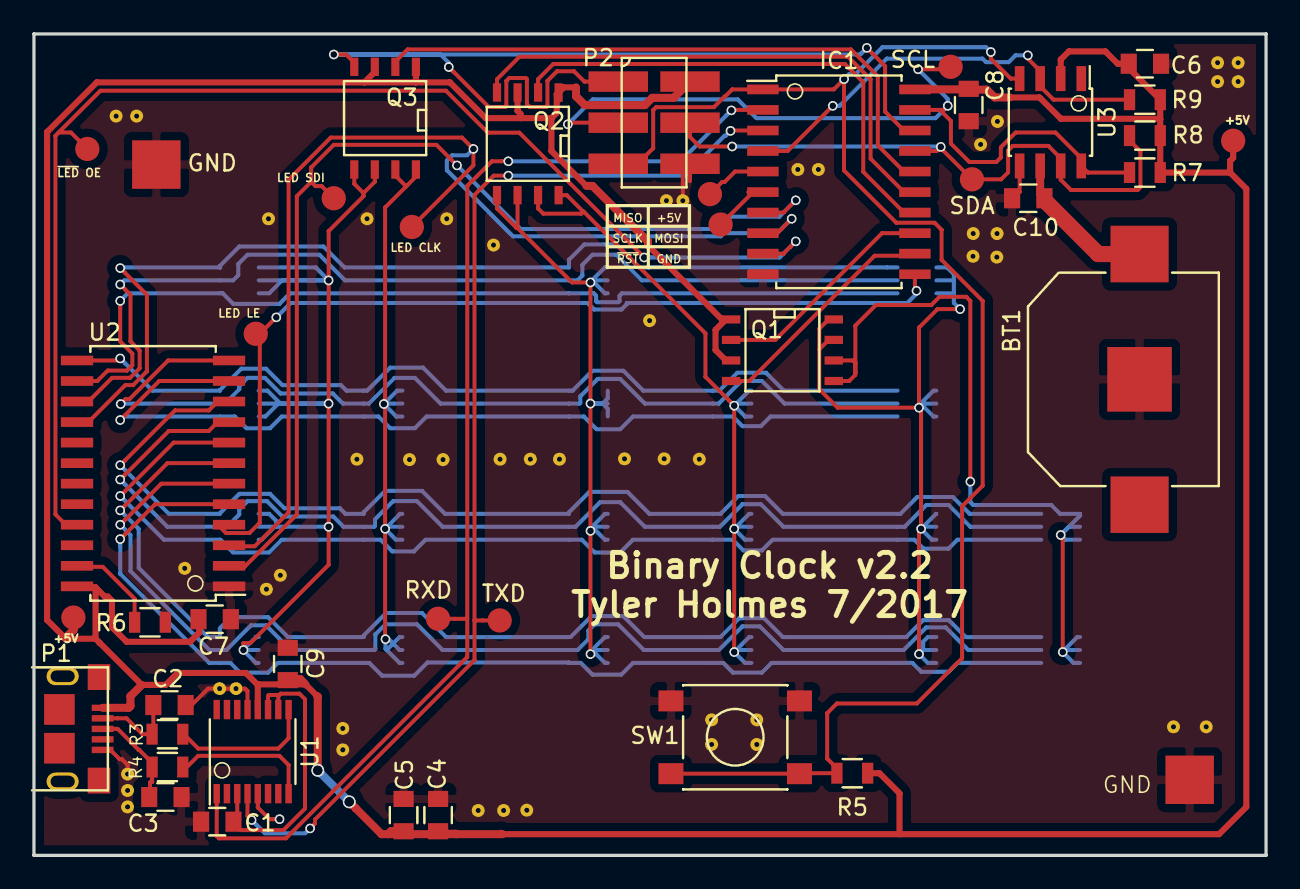
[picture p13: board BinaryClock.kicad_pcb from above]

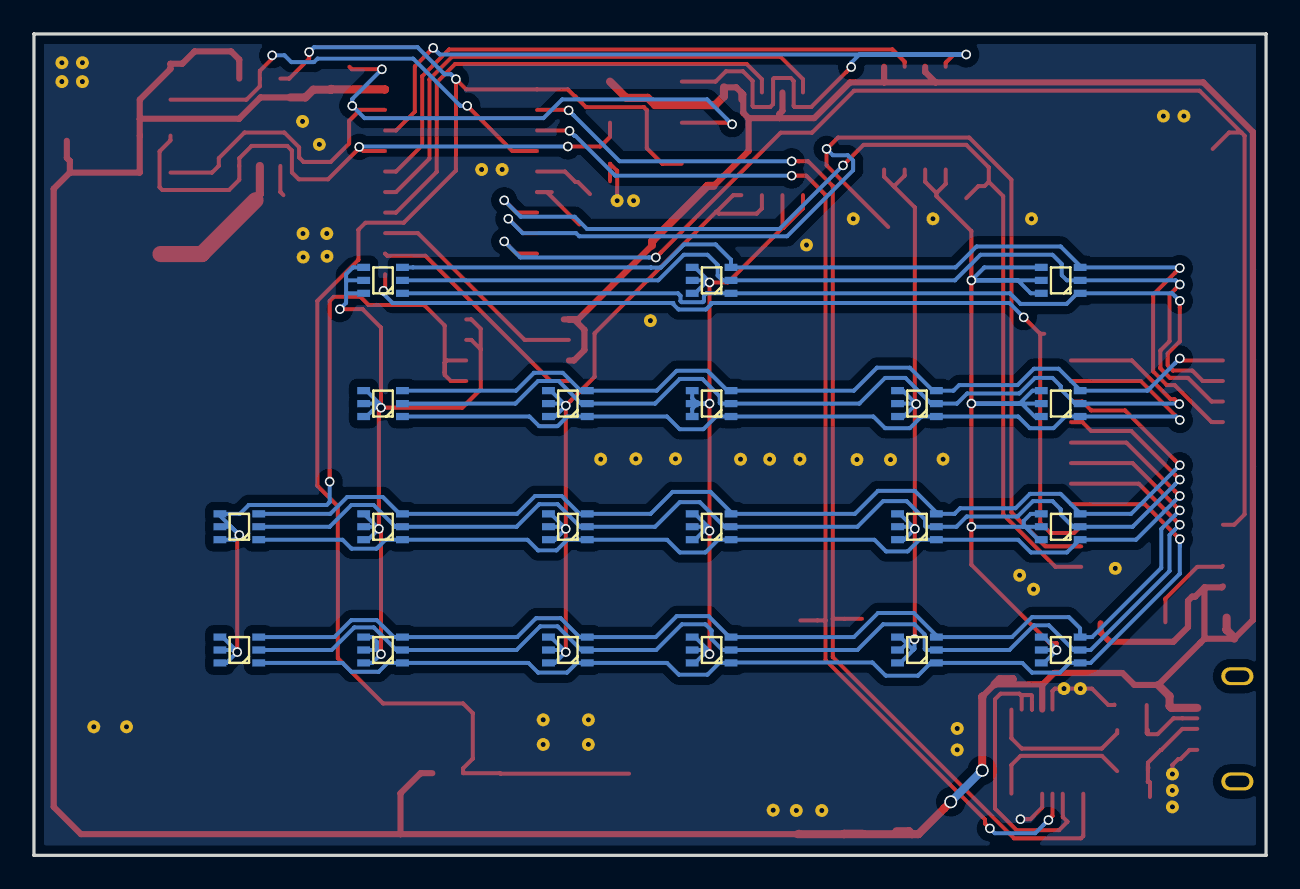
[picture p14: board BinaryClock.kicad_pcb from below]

Board: 2 copper layers, 76.2 x 50.8 mm, 62 parts (20 on the bottom side), 45 nets.

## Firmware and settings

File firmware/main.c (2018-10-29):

/* Author: Tyler Holmes
 * Copyright: TBD
 * License: TBD
 */

#include <avr/io.h>
#include "timer_4313.h"
#include "RTC_DS3231.h"
#include "LED.h"
// #include "LED_drvr_STP16CPC26.h"
#include "UART.h"
#include "i2c.h"
#include "hardware.h"
#include "color.h"
#include "ports.h"
#include "global_defines.h"
#include <stdint.h>

/*! \file main.c
    \brief  Main logic of the Binary Clock firmware. Handles calling all other functions
    other than interrupt driven ISRs.
*/

#define COMMAND_LENGTH 6   //!< number of bytes in a valid UART command.

//! Current state of the clock.
typedef enum {
    RUN_TIME,   //!< Runs time display mode. LEDs controlled by the current time.
    RUN_MANUAL  //!< Runs manual display mode. LEDs controlled by UART commands.
} state_t;

state_t system_state = RUN_TIME;   //!< keeps track of the system state.
uint8_t uart_command_received = 0; //!< valid command received flag.
// uint8_t timer_expired = 0;         //!< 15-20ish ms timer timeout flag.
uint8_t LED_multiplex_timer_count = 0;   //!< count of mutiplex handler timer events.
uint8_t command_buffer[COMMAND_LENGTH];  //!< where UART commands are buffered.

// private function declarations
static void process_UART_command(rtc_time_t *time_ptr, uint8_t *cmd_buffer);
static void increment_time(rtc_time_t *rtc_time_ptr, uint8_t inc_ammount);


/*!
 * Runs the main program.
 *
 * Order of opperation:
 *   1. Check if we've received enough data for a command.
 *     - If we have, process it.
 *   2. Check if we should run manual control or time control.
 *     - If manual control:
 *        a. run the LED multiplex function.
 *        b. keep time as well.
 *     - If time control:
 *        a. check if we need to update the time
 *           - if so, increment time and update the LED array
 *        b. run the LED multiplex function
 */
int main(void)
{
    volatile uint8_t multiplexer_count;
    volatile uint8_t rtc_1hz_int_count;
    LED_color_t color;
    LED_color_t* color_ptr = &color;
    uint8_t time_diff;
    // uint8_t time_updated = FALSE;
    uint8_t start_byte_received = FALSE;
    retval_t retval = GEN_FAIL;
    rtc_time_t time;
    rtc_time_t *t_ptr = &time;

    hardware_init();
    LED_init();
    timer_init(&multiplexer_count);
    UART_init();
    i2c_init();
    retval = RTC_init(t_ptr, &rtc_1hz_int_count);
    load_colors(color_ptr);
    LED_set_color(color_ptr->red, color_ptr->blue, color_ptr->green);
    LED_update_time(t_ptr);

    ///// main while loop /////
    while(1) {
        // check if we have UART data to handle
        if (UART_receive_unread_items() >= COMMAND_LENGTH) {
            // check if we haven't received a start byte yet
            if (start_byte_received == FALSE) {
                // check for the start byte
                do {
                    UART_receive_byte(command_buffer, TRUE);
                    if (command_buffer[0] == UART_CMD_START_BYTE) {
                        start_byte_received = TRUE;
                        break;
                    }
                } while(UART_receive_unread_items() != 0);
            } else {
                // We've received the start byte. Handle the command (if enough data)
                if (UART_receive_unread_items() >= COMMAND_LENGTH) {
                    // get the data
                    UART_receive(command_buffer, COMMAND_LENGTH);
                    // procress the received command
                    process_UART_command(t_ptr, command_buffer);
                    start_byte_received = FALSE;  // reset start byte
                }
            }
        }

        // run the system
        if (rtc_1hz_int_count != 0) {
            time_diff = rtc_1hz_int_count;
            // could lose a tick here if our timing really sucks
            rtc_1hz_int_count = 0;
            increment_time(t_ptr, time_diff);
            // update the LED setting if we're in RUN_TIME mode
            if (system_state == RUN_TIME) {
                LED_update_time(t_ptr);
            }
        }

        // Run multiplexer of time at 2.874 kHz (what we need for 4 bit color per color)
        if (multiplexer_count != 0) {
            multiplexer_count = 0;
            LED_run();
        }

        // // every day, re-check with RTC to update time. Will try for a minute if unsuccessful
        // if (t_ptr->hour == 3 && t_ptr->minute == 0 && time_updated == FALSE) {
        //     retval = RTC_read_time(t_ptr);
        //     if (retval == GEN_PASS) {
        //         time_updated = TRUE;
        //     }
        // } else if (t_ptr->hour == 3 && t_ptr->minute == 1) {
        //     // reset it for tomorrow
        //     time_updated = FALSE;
        // }
        // let UART commands update the LEDs, but continue to refresh them
    }
}


/*!
 * Processes a received UART command. Here's a list of commands:
 *   1. UART_CMD_SET_LED:
 *       - Sets an individual LED to a certain color. Must be in manual
 *         control mode.
 *   1. UART_CMD_CLEAR_LED:
 *       - Clears an individual LED. Must be in manual control mode.
 *   1. UART_CMD_CLEAR_ALL_LED:
 *       - Clears all LEDs. Must be in manual control mode.
 *   1. UART_CMD_SET_ALL_LED:
 *       - Sets all LEDs to a certain color. Must be in manual
 *         control mode.
 *   1. UART_CMD_SET_TIME:
 *       - Sets the time. Must be in time control mode.
 *   1. UART_CMD_SET_COLOR:
 *       - Sets the color of the LEDs when running in time control mode.
 *   1. UART_CMD_CHANGE_STATE:
 *       - Changes the state the board is running in.
 *
 * @param[in] time_ptr (rtc_time_t *): Pointer that is used to keep track of the time.
 * @param[in] cmd_buffer (uint8_t *): Buffer that holds the bytes in the command.
 */
void process_UART_command(rtc_time_t *time_ptr, uint8_t *cmd_buffer)
{
    switch(cmd_buffer[0]) {
        case UART_CMD_SET_LED: {
            if (system_state != RUN_MANUAL) {
                UART_transmit_byte(UART_CMD_WRONG_STATE, TRUE);
                break;
            }
            // bytes 1 & 2 is row & column, bytes 3, 4, & 5 is red, green, and blue vals
            LED_set(cmd_buffer[1], cmd_buffer[2], cmd_buffer[3], cmd_buffer[4], cmd_buffer[5]);
            UART_transmit_byte(UART_CMD_VALID, TRUE);
            break;
        }

        case UART_CMD_CLEAR_LED: {
            if (system_state != RUN_MANUAL) {
                UART_transmit_byte(UART_CMD_WRONG_STATE, TRUE);
                break;
            }
            // bytes 1 & 2 is row & column
            LED_clear(cmd_buffer[1], cmd_buffer[2]);
            UART_transmit_byte(UART_CMD_VALID, TRUE);
            break;
        }

        case UART_CMD_CLEAR_ALL_LED: {
            if (system_state != RUN_MANUAL) {
                UART_transmit_byte(UART_CMD_WRONG_STATE, TRUE);
                break;
            }
            // clear all LEDs
            LED_clear_all();
            UART_transmit_byte(UART_CMD_VALID, TRUE);
            break;
        }

        case UART_CMD_SET_ALL_LED: {
            if (system_state != RUN_MANUAL) {
                UART_transmit_byte(UART_CMD_WRONG_STATE, TRUE);
                break;
            }
            // Bytes 1, 2, and 3 is red, green and blue values
            LED_set_all(cmd_buffer[1], cmd_buffer[2], cmd_buffer[3]);
            UART_transmit_byte(UART_CMD_VALID, TRUE);
            break;
        }

        case UART_CMD_SET_TIME: {
            if (system_state != RUN_TIME) {
                UART_transmit_byte(UART_CMD_WRONG_STATE, TRUE);
                break;
            }
            // Byte 1: Hour, Byte 2: Min, Byte 3: sec
            RTC_set_time(time_ptr, cmd_buffer[1], cmd_buffer[2], cmd_buffer[3]);
            UART_transmit_byte(UART_CMD_VALID, TRUE);
            break;
        }

        case UART_CMD_SET_COLOR: {
            if (system_state != RUN_TIME) {
                UART_transmit_byte(UART_CMD_WRONG_STATE, TRUE);
                break;
            }
            // Byte 1: Red, Byte 2: Green, Byte 3: Blue
            LED_set_color(cmd_buffer[1], cmd_buffer[2], cmd_buffer[3]);
            UART_transmit_byte(UART_CMD_VALID, TRUE);
            break;
        }

        case UART_CMD_CHANGE_STATE: {
            if (cmd_buffer[1] == 0) {
                system_state = RUN_TIME;
                LED_update_time(time_ptr);
            } else if (cmd_buffer[1] == 1) {
                system_state = RUN_MANUAL;
            }
            UART_transmit_byte(UART_CMD_VALID, TRUE);
            break;
        }

        default: {
            UART_transmit_byte(UART_CMD_INVALID, TRUE);
            break;
        }
    }
}


/*!
 * Increments the time admin pointer to keep track of the time.
 *
 * @param[in] time_ptr (rtc_time_t *): Pointer that is used to keep track of the time.
 * @param[in] inc_ammount (uint8_t): Ammount to increment by.
 */
void increment_time(rtc_time_t *rtc_time_ptr, uint8_t inc_ammount)
{
    rtc_time_ptr->second += inc_ammount;
    if (rtc_time_ptr->second >= 60) {
        rtc_time_ptr->second -= 60;
        rtc_time_ptr->minute += 1;
        if (rtc_time_ptr->minute >= 60) {
            rtc_time_ptr->minute -= 60;
            rtc_time_ptr->hour += 1;
            if (rtc_time_ptr->hour >= 24) {
                rtc_time_ptr->hour -= 24;
            }
        }
    }
}

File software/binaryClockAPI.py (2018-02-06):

#!/usr/bin/env python
'''
API functions for interfacing with the Binary Clock
'''
import serial
import time
import os
import sys
import binascii
import struct
import glob

# just for my python3 linter to shut up...
if sys.version_info.major == 3:
    raw_input = input


class BinaryClockAPI:
    """
    Main class that handles communication and exposes functions to be called.

    :param str serial_port: Serial port to connect to. (e.g. "/dev/tty.usbserial-12345")
    :param int baud: baudrate to communicate at (default: 250000)
    """
    def __init__(self, serial_port, baud=250000):
        # Start byte
        self.UART_START_BYTE = 0xAA
        # Command bytes
        self.UART_CMD_SET_LED = 0x10
        self.UART_CMD_CLEAR_LED = 0x11
        self.UART_CMD_CLEAR_ALL_LED = 0x12
        self.UART_CMD_SET_ALL_LED = 0x13
        self.UART_CMD_SET_TIME = 0x14
        self.UART_CMD_SET_COLOR = 0x15
        self.UART_CMD_CHANGE_STATE = 0x16
        # error codes
        self.UART_CMD_INVALID = 0xFF
        self.UART_CMD_WRONG_STATE = 0xFE
        # valid command
        self.UART_CMD_VALID = 0x42
        self.STATE_RUN_TIME = 0
        self.STATE_RUN_MANUAL = 1
        self.coms = serial.Serial(port=serial_port, baudrate=baud, timeout=3)

    def close(self):
        """ Closes the com port to the device"""
        self.coms.close()

    def set_LED(self, row, column, red, green, blue):
        """
        Set an LED to the given color.

        :param int row: Row of the LED to set
        :param int column: Column of the LED to set
        :param int red: Red value (0 - 255)
        :param int green: Green value (0 - 255)
        :param int blue: Blue value (0 - 255)
        """
        self.coms.write(struct.pack("B", self.UART_START_BYTE))
        self.coms.write(struct.pack("B", self.UART_CMD_SET_LED))
        self.coms.write(struct.pack("B", row))
        self.coms.write(struct.pack("B", column))
        self.coms.write(struct.pack("B", red))
        self.coms.write(struct.pack("B", green))
        self.coms.write(struct.pack("B", blue))
        response = self.coms.read(size=1)
        return binascii.hexlify(response)

    def update_time(self, time_override_arr=None):
        """
        Function for updating the time displayed on the clock. By default, uses
        time.localtime() function to grab the current time from your computer.

        :param list time_override_arr: List (in the format [hour, min, sec]) if you want to
            override the local time on your machine.
        """
        if time_override_arr is None:
            time_vals = time.localtime()
            hour = time_vals[3]
            minute = time_vals[4]
            second = time_vals[5]
        else:
            hour = time_override_arr[0]
            minute = time_override_arr[1]
            second = time_override_arr[2]
        self.coms.write(struct.pack("B", self.UART_START_BYTE))
        self.coms.write(struct.pack("B", self.UART_CMD_SET_TIME))
        self.coms.write(struct.pack("B", hour))
        self.coms.write(struct.pack("B", minute))
        self.coms.write(struct.pack("B", second))
        self.coms.write(struct.pack("B", 0))
        self.coms.write(struct.pack("B", 0))
        response = self.coms.read(size=1)
        return binascii.hexlify(response)

    def clear_LED(self, row, column):
        """Clear an LED at the given co-ordinates.

        :param int row: Row of the LED to clear
        :param int column: Column of the LED to clear
        """
        self.coms.write(struct.pack("B", self.UART_START_BYTE))
        self.coms.write(struct.pack("B", self.UART_CMD_CLEAR_LED))
        self.coms.write(struct.pack("B", row))
        self.coms.write(struct.pack("B", column))
        self.coms.write(struct.pack("B", 0))
        self.coms.write(struct.pack("B", 0))
        self.coms.write(struct.pack("B", 0))
        response = self.coms.read(size=1)
        return binascii.hexlify(response)

    def clear_all_LEDs(self):
        """Clears all LEDs."""
        self.coms.write(struct.pack("B", self.UART_START_BYTE))
        self.coms.write(struct.pack("B", self.UART_CMD_CLEAR_ALL_LED))
        self.coms.write(struct.pack("B", 0))
        self.coms.write(struct.pack("B", 0))
        self.coms.write(struct.pack("B", 0))
        self.coms.write(struct.pack("B", 0))
        self.coms.write(struct.pack("B", 0))
        response = self.coms.read(size=1)
        return binascii.hexlify(response)

    def set_all_LEDs(self, red, green, blue):
        """
        Sets all LEDs to the given color.

        :param int red: Red value (0 - 255)
        :param int green: Green value (0 - 255)
        :param int blue: Blue value (0 - 255)
        """
        self.coms.write(struct.pack("B", self.UART_START_BYTE))
        self.coms.write(struct.pack("B", self.UART_CMD_SET_ALL_LED))
        self.coms.write(struct.pack("B", red))
        self.coms.write(struct.pack("B", green))
        self.coms.write(struct.pack("B", blue))
        self.coms.write(struct.pack("B", 0))
        self.coms.write(struct.pack("B", 0))
        response = self.coms.read(size=1)
        return binascii.hexlify(response)

    def set_color(self, red, green, blue):
        """
        Sets the active colors when running in time mode.

        :param int red: Red value (0 - 255)
        :param int green: Green value (0 - 255)
        :param int blue: Blue value (0 - 255)
        """
        self.coms.write(struct.pack("B", self.UART_START_BYTE))
        self.coms.write(struct.pack("B", self.UART_CMD_SET_COLOR))
        self.coms.write(struct.pack("B", red))
        self.coms.write(struct.pack("B", green))
        self.coms.write(struct.pack("B", blue))
        self.coms.write(struct.pack("B", 0))
        self.coms.write(struct.pack("B", 0))
        response = self.coms.read(size=1)
        return binascii.hexlify(response)

    def set_state(self, state):
        """
        Sets the current state of the device. (either time control or manual control)

        :param int state: Can either be 0 (RUN TIME) or 1 (RUN MANUAL)
        """
        if state != 0 and state != 1:
            raise ValueError("State must either be a 0 or a 1!")
        self.coms.write(struct.pack("B", self.UART_START_BYTE))
        self.coms.write(struct.pack("B", self.UART_CMD_CHANGE_STATE))
        self.coms.write(struct.pack("B", state))
        self.coms.write(struct.pack("B", 0))
        self.coms.write(struct.pack("B", 0))
        self.coms.write(struct.pack("B", 0))
        self.coms.write(struct.pack("B", 0))
        response = self.coms.read(size=1)
        return binascii.hexlify(response)
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

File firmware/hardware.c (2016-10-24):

#include "hardware.h"
#include "ports.h"
#include "global_defines.h"
#include <avr/io.h>
#include <avr/interrupt.h>

/*! \file hardware.c
    \brief Initialization of basic hardware (port direction & initial pin
    states) goes here in hardware_init().
*/

/*!
 * Initializes all the hardware
 * @param[out] retval (retval_t): The memory area to copy to.
 */
retval_t hardware_init(void)
{
    // configure pins for input/output (1 = output, 0 = input)
    DDRA = 0x00;  // pin 0 - ind. LED, pin 1 - RTC 1 sec int.
    ANO_PORT = 0xFF; // make sure LEDs don't turn on
    DDRB = (1 << PB6) | (1 << PB4) | (1 << PB3) | (1 << PB2) | (1 << PB1) | (1 << PB0);
    DDRD = 0xFE;  // all outputs except UART RX
    sei();
    return GEN_PASS;
}

/*!
 * Writes to the internal EEPROM
 * @param[in] address (uint8_t): Address to write to
 * @param[in] data_to_write (uint8_t): Data to write
 */
void EEPROM_write(uint8_t address, uint8_t data_to_write)
{
    // Wait for completion of previous write
    while(EECR & (1<<EEPE));
    cli();  // disable all interrupts
    // Set Programming mode
    EECR = ((0 << EEPM1) | (0 << EEPM0));
    // Set up address and data registers
    EEAR = address;
    EEDR = data_to_write;
    // Write logical one to EEMPE
    EECR |= (1<<EEMPE);
    // Start eeprom write by setting EEPE
    EECR |= (1<<EEPE);
    sei();  // re-enable interrupts
}


/*!
 * Reads from the internal EEPROM
 * @param[in] address_to_read (uint8_t): Address to read from
 * @param[out] data_read (uint8_t): Data read from the address
 */
uint8_t EEPROM_read(uint8_t address_to_read)
{
    // Wait for completion of previous write
    while(EECR & (1<<EEPE));
    cli();  // disable all interrupts
    // Set up address register
    EEAR = address_to_read;
    // Start eeprom read by writing EERE
    EECR |= (1<<EERE);
    sei();  // re-enable interrupts
    // Return data from data register
    return EEDR;
}

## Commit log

2016-07-26 Added many new files
    Added a UART driver, UART functionality, a general purpose ring buffer,
    and some minor other changes
2016-07-27 Updated makefile to add fuse bit descriptions
2016-07-31 A lot of structural changes
    Rethought many structural things. Thoughts in plan_of_attack.txt. Will
    most likely change most of the LED and LED driver code
2016-07-31 Roughing out new LED functionality
2016-07-31 Changed naming scheme 'LEDs' to 'LED'
    brings more unification to naming across files
2016-08-04 Major overhaul of the LED driver section.
    The change is mostly done in this implementation and is compiling. No
    testing yet.
2016-08-05 added i2c functionality and some compiled binaries
2016-08-08 developing i2c & rtc library
2016-08-12 added many things
    I should break this commit up into multiple….
2016-08-13 i2c and etc development
2016-08-14 Updates to many files, added a test project to verify the LED driver
2016-08-22 Many things
    - changed to retval_t and bool_t types
    - made UART work
2016-08-22 many changes as usual
    - UART added functionality
    - I2C almost works
    - changed I2C to bit bang, will most likely switch to an ifdef for bit
    bang mode vs. USI mode
2016-08-22 Update i2c.c
    Change read write mask logic
2016-08-23 Added a bitang ifdef in the i2c driver
2016-08-23 fleshed out i2c bitbang & deleted ringbuffertest project
2016-08-23 I2C Improvements
    Write seems to be working 100%
    Read isn’t. It isn’t seeing NACKs and isn’t writing the address to be
    read from it seems
2016-08-24 working with RTC interrupt
    Prototype working with RTC (read / write with 1 hz interrupt for time
    keeping)
2016-08-26 added UART receive length detection & refactored main to accept UART commands
2016-08-28 fixed port issue
    Does not crash if no com device plugged in. Now refreshes list on click
    of the dropdown menu
    Also made Mac return usbserial ports without checking if you can
    connect. (much faster)
    [CustomGUIWrappers.py, binaryClockAPI.py, binaryClockGUI.py]
2016-08-29 UART commands now check for start byte
    in order to avoid getting out of sync until powercycle, we start with 0xAA in all commands. Still need to change python API to reflect these changes
    [CustomGUIWrappers.py, binaryClockGUI.py, main.c]
2016-08-30 many things...
    -get rid of tracking multiplexer count
    -switch order of clearing multiplexer count and rtc count to avoid
    falsely clearing it
    -add start_byte_received reset to FALSE after processing a command
    [main.c]
2016-09-03 Adding in PCB files
    [015910060.obj, 015910060.stp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]
2016-09-25 Fixed routing issues, fixed paste layer issues, and eliminated electrolytic caps
    [Binary Clock.xlsx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]
2016-09-26 Added a UART_peak_byte function & ring_buffer_peak_data function
2016-09-26 Deleted the not-needed silkscreen on the LEDs side of the PCB
    [BinaryClock-B.SilkS.gbr]
2016-09-30 Adding the positioning files for automated assembly
    [BinaryClock-bottom-pos-file.csv, BinaryClock-top-pos-file.csv]
2016-10-08 Changed led_color_t to LED_color_t
    [BinaryClock.xls]
2016-10-16 Refactored based on the UART start byte and what it returns
    [BinaryClock.kicad_pcb]
2016-10-17 refactored to decrease size and added some functionality to check if the RTC oscillator stopped when in battery backup mode.
    [RTC_DS3231.c, main.c]
2016-10-24 Saving clock color and fixing the GUI
    [BinaryClock.kicad_pcb]
2017-06-20 making some minor formatting changes
    [BinaryClock.kicad_pcb]
2017-06-20 minor changes for 2.2 release
    [BinaryClock-B.Cu.gbr, BinaryClock-B.Mask.gbr, BinaryClock-B.Paste.gbr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]
2017-12-22 some more cleanup and hide silk on LED side of PCB
    [BinaryClock.kicad_pcb]
2018-02-06 adding comment about fuse byte
2018-10-29 v2 schematic
